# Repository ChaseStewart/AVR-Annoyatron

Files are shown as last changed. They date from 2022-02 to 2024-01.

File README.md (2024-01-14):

# AVR-Annoyatron
Documentation (https://chasestewart.github.io/AVR-Annoyatron/)

Rebuilding an undergrad embedded systems final project to reflect new knowledge and skills on a different MCU

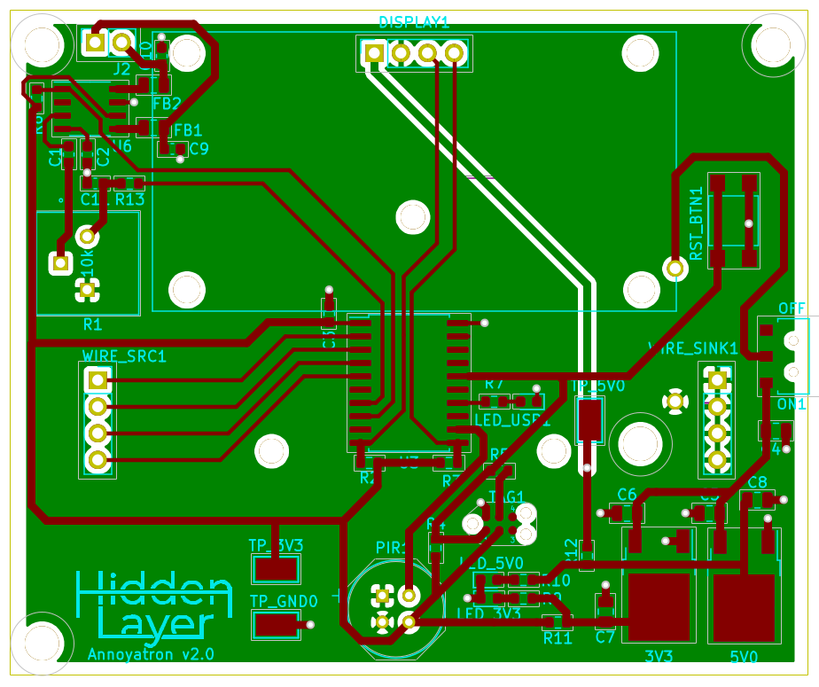
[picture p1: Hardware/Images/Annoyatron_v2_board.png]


# Author
[Chase E. Stewart](https://chasestewart.co) for [Hidden Layer Design](https://hiddenlayerdesign.com)

# Repository Layout
`/Hardware/Images/...` - Embeddable images of the schematic and board layout

`/Hardware/Board_Files/...` - Gerber files that can be used to order the circuit board

`/Software/AnnoyatronFW/...` - Firmware for the Annoyatron project, in the form of a Microchip Studio project

# Guides
* To learn more about Audio, read [here](Software/AnnoyatronFW/audio/README.md)
* To learn more about Programming the board, read [here](Software/README.md)

# Setup Instructions

## Hardware
* Order the board from a PCB manufacturer using the Board_Files
* Order the parts from an electronics company using `/Hardware/Annoyatron_v2_BOM.csv`
* Assemble the PCB

## Software
* Download [Python 3.10](https://www.python.org/) or similar if you don't have it (don't go too far back) and put it in your executable path
* Download [pymcuprog](https://pypi.org/project/pymcuprog/) using pip or whatever works
* Download [Microchip Studio](https://www.microchip.com/en-us/tools-resources/develop/microchip-studio) and load the project from `/Software/AnnoyatronFw/...`
* Set up the custom programming tool in Microchip Studio to suit your configuration 
  - Mine was `pymcuprog write -t uart -d attiny1606 -u COM12 -f "$(MSBuildProjectDirectory)\Debug\AnnoyatronFW.hex" -v info -c 57600 --verify`
* Acquire a [Tag-Connect programming tool](https://www.tag-connect.com/product/tc2030-pkt-icespi-nl) and connect it to a [USB-to-serial dongle](https://www.sparkfun.com/products/12731) to do the flashing 
  - *NOTE: Don't install a battery until you've successfully flashed the code and the board appears to be working over USB power!!*
* You will need to use a `pymcuprog` erase command between every flash to make sure your program will be successfully verified
  - Mine was `pymcuprog erase -t uart -u COM12 -d attiny1606`

## Running the program
* Remove the programming header and install a 9-volt battery
* Turn on the power using the switch
* Move or wave to trigger the PIR sensor, and then cut the proper wire before time runs out

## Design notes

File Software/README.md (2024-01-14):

# Programming the board

## Programming Interface
This project uses the [UPDI Programming Interface](https://onlinedocs.microchip.com/pr/GUID-DDB0017E-84E3-4E77-AAE9-7AC4290E5E8B-en-US-4/index.html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) in order to flash the ATTiny1606 with code changes. In this project, the TagConnect 6 pin No Legs footprint was used for programming to save board space and to avoid populating a big 2x3 header. 

## Hardware Needed
You will need the following to flash your board
* A USB cable
* A populated Annoyatron Board
* An [FTDI](https://www.adafruit.com/product/284)-to-[USB interface](https://www.sparkfun.com/products/9873) - Many options are available and counterfeit chips can be found, but Sparkfun and Adafruit are probably safe bets if you don't know what to get
* A [TagConnect TC2030-PKT-NL 6-pin connector](https://www.digikey.com/en/products/detail/tag-connect-llc/TC2030-PKT-NL/18713762)
* A [TagConnect Board-Retaining End Clip](https://www.digikey.com/en/products/detail/tag-connect-llc/TC2050-CLIP-3PACK/12318009)

**NOTE**: I have a probably-counterfeit FTDI debugger that works for most things including communicating over UART and flashing other types of boards, but that debugger just does not work with this UPDI- this is the reason for the warning in the FTDI-to-USB entry. 

## Steps and Images
First you will need to properly connect the FTDI debugger pins to the TagConnect cable, and connect the FTDI debugger to a USB cable. When that is done it should look like this:
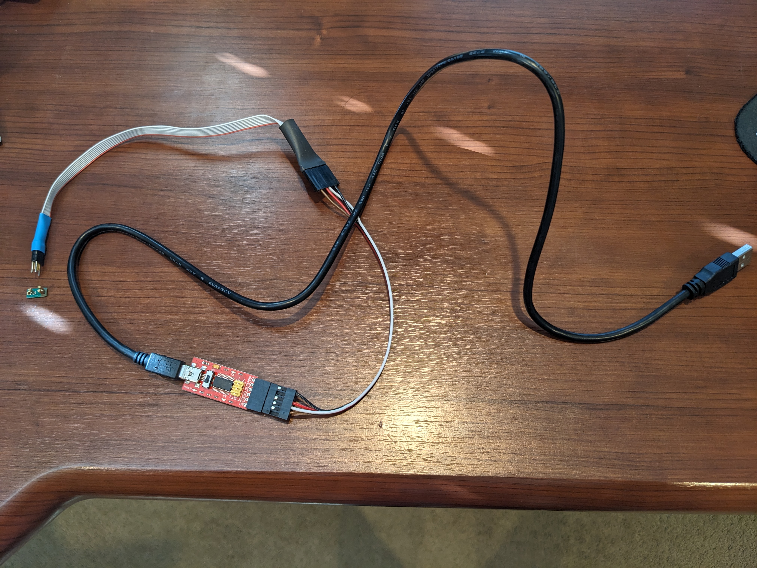
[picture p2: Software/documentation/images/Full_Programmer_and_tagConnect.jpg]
Image of the full programming tool including TagConnect cable


I wound up making a custom F-F Dupont-connector cable to ensure proper orientation (I use the black GND cable and red VCC to visually confirm orientation every time), 
but you can use jumper connectors or whatever you need. I populated the TXD, RXD, GND, and VCC pins only for this UPDI connector. 
Image of just the FTDI-to-USB device and its connector cable

Now that you have the cable, you are going to look for this `TAG1` footprint on the board that looks like this. 
The feet of the TagConnect cable will go through the holes and then the little cap can be placed on the far side of the board to secure the cable. Spring tension will keep the pogo pins electrically connected the 6 circular pins on the face of the PCB. 
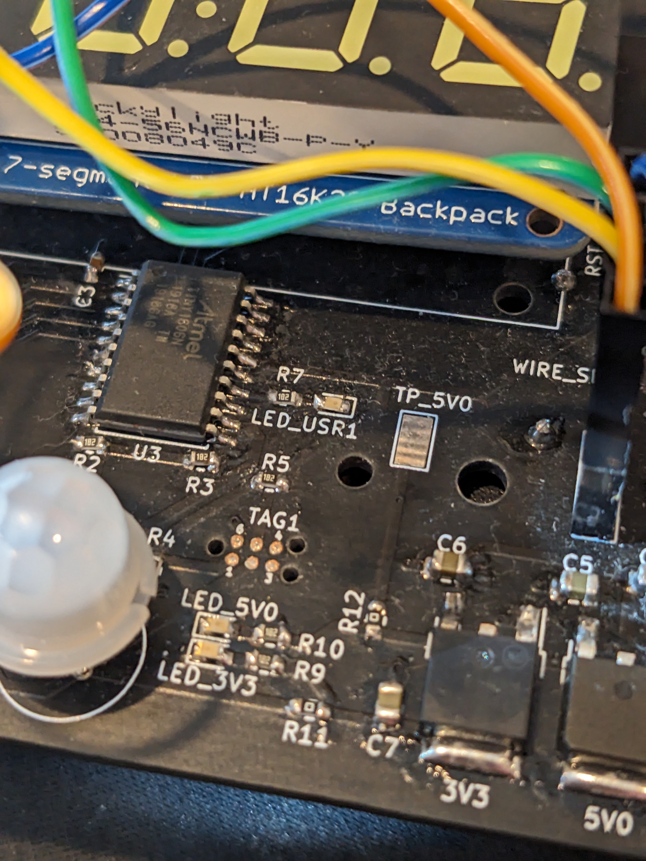
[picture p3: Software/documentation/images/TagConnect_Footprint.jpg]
Image of the location on the PCB where the TagConnect can be attached


When you put it all together it should look like this:
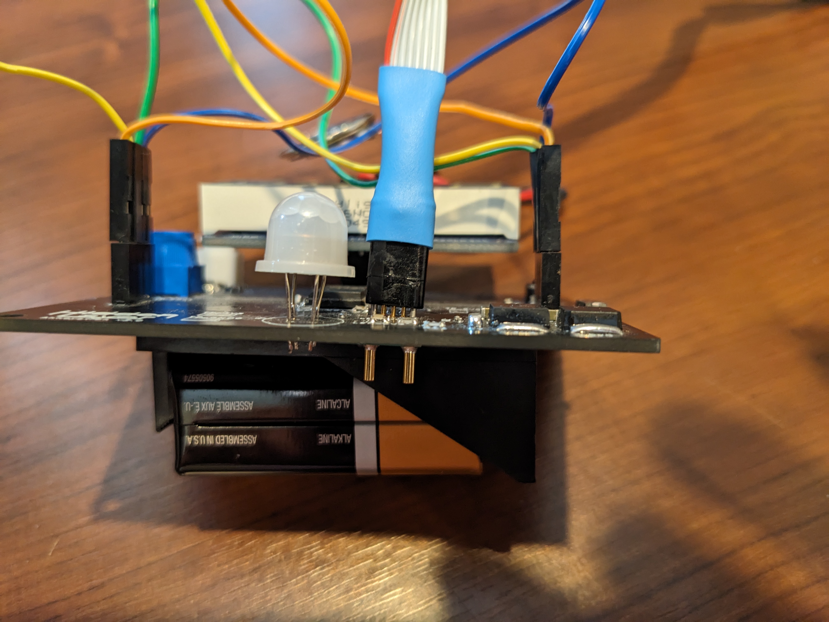
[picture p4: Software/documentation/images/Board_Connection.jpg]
Image of the TagConnect cable connected to the board


**NOTE:** When you have the board connected to a computer, **ENSURE THE 9-VOLT BATTERY IS REMOVED OR THE POWER SWITCH IS OFF**

Now use the scripts in the Scripts folder or set up a programming command in Microchip Studio and you should be able to flash your board
As a basic check, you can try to read the fuses with `ReadATTinyResetFuse.ps1`. If everything appears connected, but the UPDI check is failing, check your connector's pins to ensure TX, RX, VCC, and GND are properly connected, and you can also gently wiggle the tag-connect cable a bit and try again.

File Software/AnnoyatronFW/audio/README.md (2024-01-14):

# AUDIO Readme
This section describes audioArrays.h and the process that was undertaken to get the audio working

## Author
[Chase E Stewart](https://chasestewart.co) for [Hidden Layer Design](https://hiddenlayerdesign.com)

## Overview
The annoyatron project is configured to use [split PWM output](https://ww1.microchip.com/downloads/en/AppNotes/TB3217-Getting-Started-with-TCA-90003217A.pdf) from its [ATTiny 1606](https://ww1.microchip.com/downloads/en/DeviceDoc/ATtiny806_1606_Data_Sheet_40002029A.pdf) CPU in order to generate audio. Audio is stored as C byte arrays in flash. These are fed to the comparator of the TCA0 clock, which uses its PWM Waveform output to control an audio amplifier IC's input pin, which then goes out to a cheap electronics speaker. There are 3 sounds that are used in the project:
* Siren - A short looping frequency chirp that plays repeatedly as the timer counts down. Stops when the timer runs out or when you cut a wire or wires
* YouWin - The phrase "You Win", played once when you win (cut the right wire before time runs out)
* YouLose - The phrase "You Lose", played once when you lose (cut multiple wires, cut the wrong wire, or time runs out)

### Audio Challenges
There are a number of challenges that stymie an easy solution to the audio problem:

1. The split comparator in the TCA0 that is used for PWM audio is only 8-bit sized. So you must use 8-bit audio.
1. You have literally 16kB of flash to work with. This is rather extreme in terms of resource constraint in this day and age. NOTE this could be alleviated easily enough by adding a memory chip, but the original project this is based on was also similarly constrained.

The space constraint is such that you must squeeze every possible shortcut out of the audio such that it still mostly serves your purposes. This includes shortening, bit crushing, downsampling, filtering, and anything you could imagine. It took a lot of tricks from my ECE background and audio tricks from my studio to result in just a quick and intelligible-enough "you win!", "you lose!", and siren noise. The challenge was interesting enough to me that I felt it merited this write-up 

### Audio Solution
Here are the things I had to do in order to get the audio working such as it does now:

1. First, record "you lose" and "you win" audio under the best circumstances possible (I used a quality microphone and audio interface)
1. These should ideally be somewhere from 0.7 to 1.3 seconds long to make your later editing easier
1. Process it for great clarity including compression, breath control, and EQ
1. Ableton Live has a "Telephone Audio" EQ that mostly just band-passes only 500Hz to 2kHz which was crucial for my eventual solution
1. Export that audio in mono at the lowest bitrate and sample frequency possible in your recording software (I started with 22050Hz, 16-bit audio)
1. Now open the audio in [Audacity](https://www.audacityteam.org/), lower the project rate to 8kHz, run `Tracks->Resample->8kHz` on the whole sample
1. Compress the audio further if necessary using `Effect->Compressor...`; the default settings that come up should be fine unless you understand compression
1. If your audio is longer than 0.7 seconds for either youWin or youLose, you may find the `Effect->Change Tempo...` effect extremely helpful in getting your samples to fit within the 16kB of flash
1. [Export from Audacity in 8 bit](https://forum.audacityteam.org/t/is-there-a-way-to-convert-a-song-into-8-bit/35388) into this folder where [ParseWaveFile.py](parseWaveFile.py) exists
1. Run the parseWaveFile.py Python Helper Script to create header files 
1. Copy the C-structs generated by the Python Helper Script into audioArrays.h, covering the current youWin and youLose structs.
1. Now hit Compile in the project, and hope for no errors related to overrunning the Flash. If the code compiles it will fit properly and work in the device
1. Now test the board in success and failure case, and ensure the samples sound clear and sound like what you want. NOTE The quality just won't be that good, you have 16kB to work with! 
1. I had to slightly pitch up my audio in order to deal with some oversampling in the TCA0 code. You can do this by reopening Audacity and using `Effect->Change Pitch...` somewhere like 10-20%

NOTE: The siren noise is mostly original from the 2009/2010 project. I guess my lab partner and I had solved this one time before, but did not write up the process to fit the audio in the previous CPU last time. 

### Python Script
The recommended way to use the [ParseWaveFile.py](parseWaveFile.py) script is to download the community version of PyCharm, and make a new project in the Software/AnnoyatronFW/audio project. You can use a venv and a python3 interpreter and it should work right out of the box- the [wave library](https://docs.python.org/3/library/wave.html) that is used is a standard python library. You can bring .WAV files right into the audio/ folder, and by default your generated headers will be created in the Outputs/ folder- the .gitignore files are set up such that your inputs and outputs won't be accidentally contributed to the repository.

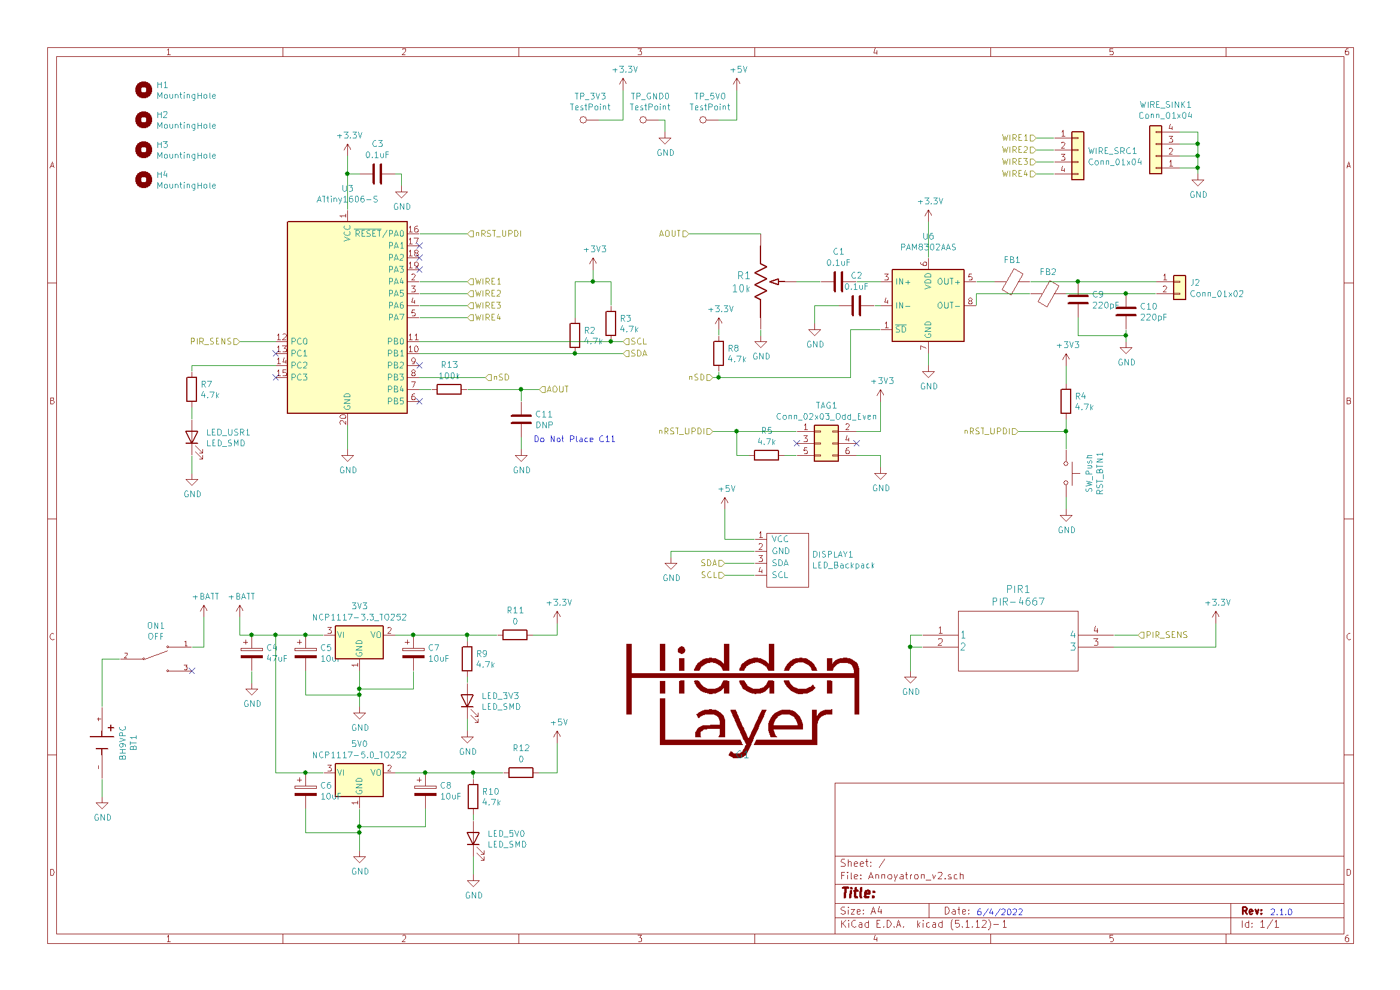
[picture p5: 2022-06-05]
Hardware/Images/Annoyatron_v2_schematic.png

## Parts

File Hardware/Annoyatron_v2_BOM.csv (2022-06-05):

Reference | Quantity | Value | Description | Footprint | Datasheet
3V3 | 1 | NCP1117-3.3_TO252 | Linear Regulator 3.3V | Package_TO_SOT_SMD:TO-252-2 | http://www.onsemi.com/pub_link/Collateral/NCP1117-D.PDF
5V0 | 1 | NCP1117-5.0_TO252 | Linear Regulator 5V | Package_TO_SOT_SMD:TO-252-2 | http://www.onsemi.com/pub_link/Collateral/NCP1117-D.PDF
BT1 | 1 | BH9VPC | 9V Battery Holder | parts:BAT_BH9VPC | https://www.memoryprotectiondevices.com/datasheets/BH9VPC-datasheet.pdf
C1 C2 C3 | 3 | 0.1uF | SMD Capacitor | Capacitor_SMD:C_0603_1608Metric | http://www.passivecomponent.com/wp-content/uploads/datasheet/WTC_MLCC_General_Purpose.pdf
C4 | 1 | 47uF | SMD Capacitor | Capacitor_SMD:C_0805_2012Metric | http://www.passivecomponent.com/wp-content/uploads/datasheet/WTC_MLCC_General_Purpose.pdf
C5 C6 C7 C8 | 4 | 10uF | SMD Capacitor | Capacitor_SMD:C_0805_2012Metric | http://www.passivecomponent.com/wp-content/uploads/datasheet/WTC_MLCC_General_Purpose.pdf
C9 C10 | 2 | 220pF | SMD Capacitor | Capacitor_SMD:C_0603_1608Metric | http://www.passivecomponent.com/wp-content/uploads/datasheet/WTC_MLCC_General_Purpose.pdf
DISPLAY1 | 1 | Adafruit_1002 | LED Display Backpack | custom:LED_Backpack | https://cdn-shop.adafruit.com/datasheets/ht16K33v110.pdf
FB1 FB2 | 2 | Ferrite_Bead | SMD Ferrite Bead | Capacitor_SMD:C_0805_2012Metric | https://www.we-online.com/katalog/datasheet/74279207.pdf
J2 | 1 | Conn_01x02 | JST Male 01x02 Conn | Connector_PinSocket_2.54mm:PinSocket_1x02_P2.54mm_Vertical | https://www.jst-mfg.com/product/pdf/eng/eEH.pdf
LED_USR1 LED_3V3 LED_5V0 | 3 | LED_SMD | SMD LED | LED_SMD:LED_0603_1608Metric | https://www.we-online.com/katalog/datasheet/150060VS55040.pdf
ON1 | 1 | SW_AYZ0102AGRLC | Switch | parts:SW_AYZ0102AGRLC | https://www.ckswitches.com/media/1431/ayz.pdf
PIR1 | 1 | PIR-4667 | PIR Sensor | footprints:4667 | https://cdn-shop.adafruit.com/product-files/4667/4667_C15116.pdf
R1 | 1 | 10k | Trim Pot 10k | custom:3386P-1-103TLF | https://www.bourns.com/docs/Product-Datasheets/3386.pdf
R11 R12 | 2 | 0 | SMD Resistor | Resistor_SMD:R_0603_1608Metric | https://www.yageo.com/upload/media/product/productsearch/datasheet/rchip/PYu-RC_Group_51_RoHS_L_11.pdf
R13 | 1 | 100k | SMD Resistor | Resistor_SMD:R_0603_1608Metric | https://www.yageo.com/upload/media/product/productsearch/datasheet/rchip/PYu-RC_Group_51_RoHS_L_11.pdf
R2 R3 R4 R5 R7 R8 R9 R10 | 8 | 4.7k | SMD Resistor | Resistor_SMD:R_0603_1608Metric | https://www.yageo.com/upload/media/product/productsearch/datasheet/rchip/PYu-RC_Group_51_RoHS_L_11.pdf
RST_BTN1 | 1 | SW_Push | Pushbutton | Button_Switch_SMD:SW_SPST_TL3305A | https://sten-eswitch-13110800-production.s3.amazonaws.com/system/asset/product_line/data_sheet/213/TL3305.pdf
TAG1 | 1 | Conn_02x03_Odd_Even | Tag-Connect 6pin No Legs | custom:TC2030-IDC-NL | https://www.tag-connect.com/wp-content/uploads/bsk-pdf-manager/2019/12/TC2030-IDC-NL-Datasheet-Rev-B.pdf
TP_GND0 TP_3V3 TP_5V0 | 3 | TestPoint | Test Points | TestPoint:TestPoint_Keystone_5019_Minature | https://www.keyelco.com/product-pdf.cfm?p=1357
U3 | 1 | ATtiny1606-S | ATTiny1606 Microcontroller | Package_SO:SOIC-20W_7.5x12.8mm_P1.27mm | http://ww1.microchip.com/downloads/en/DeviceDoc/ATtiny806_1606_Data_Sheet_40002029A.pdf
U6 | 1 | PAM8302AAS | IC Class-D Audio Amplifier | Package_SO:SOP-8_3.9x4.9mm_P1.27mm | https://www.diodes.com/assets/Datasheets/PAM8302A.pdf
WIRE_SINK1 WIRE_SRC1 | 2 | Conn_01x04 | Female 01x04 Header Socket | Connector_PinSocket_2.54mm:PinSocket_1x04_P2.54mm_Vertical | https://app.adam-tech.com/products/download/data_sheet/203013/rs1-xx-g-data-sheet.pdf
SPEAKER | 1 | CDM-20008 | Speaker | N/A | https://www.cuidevices.com/product/resource/cdm-20008.pdf

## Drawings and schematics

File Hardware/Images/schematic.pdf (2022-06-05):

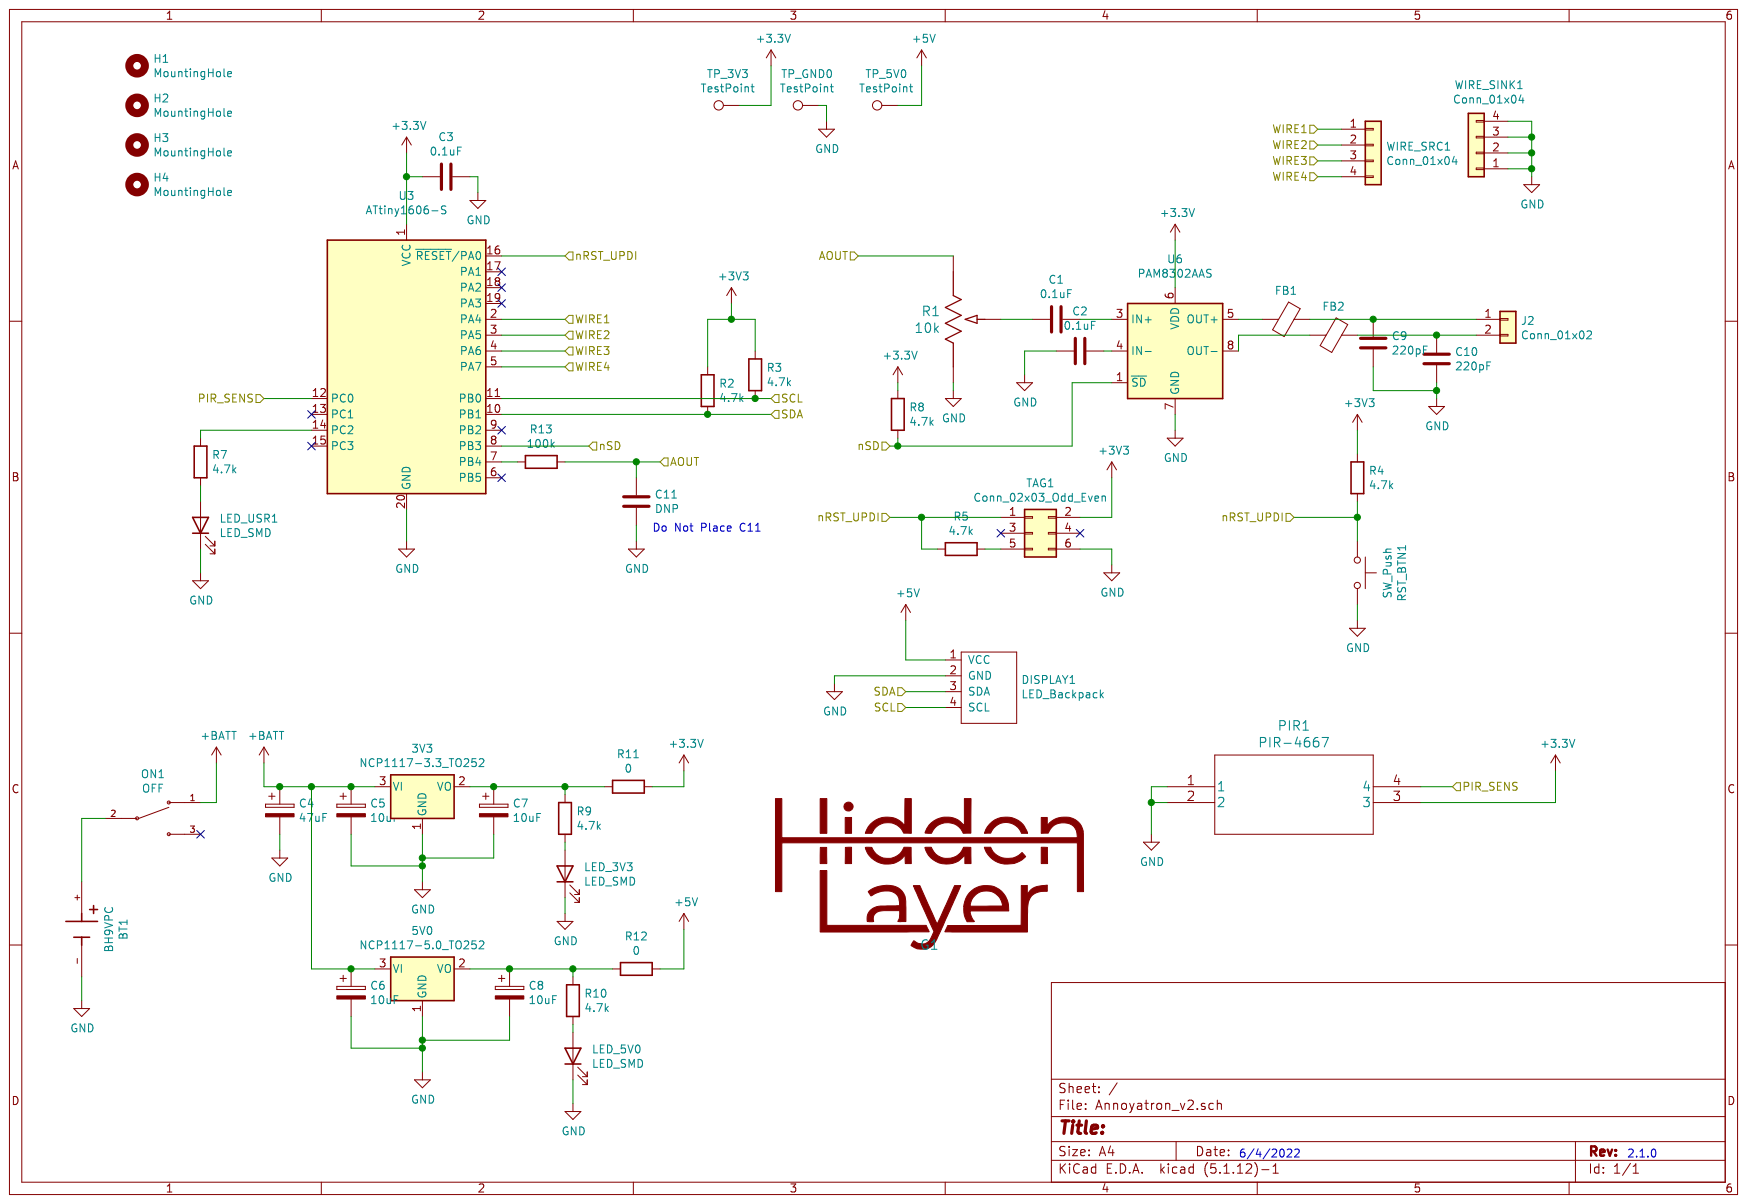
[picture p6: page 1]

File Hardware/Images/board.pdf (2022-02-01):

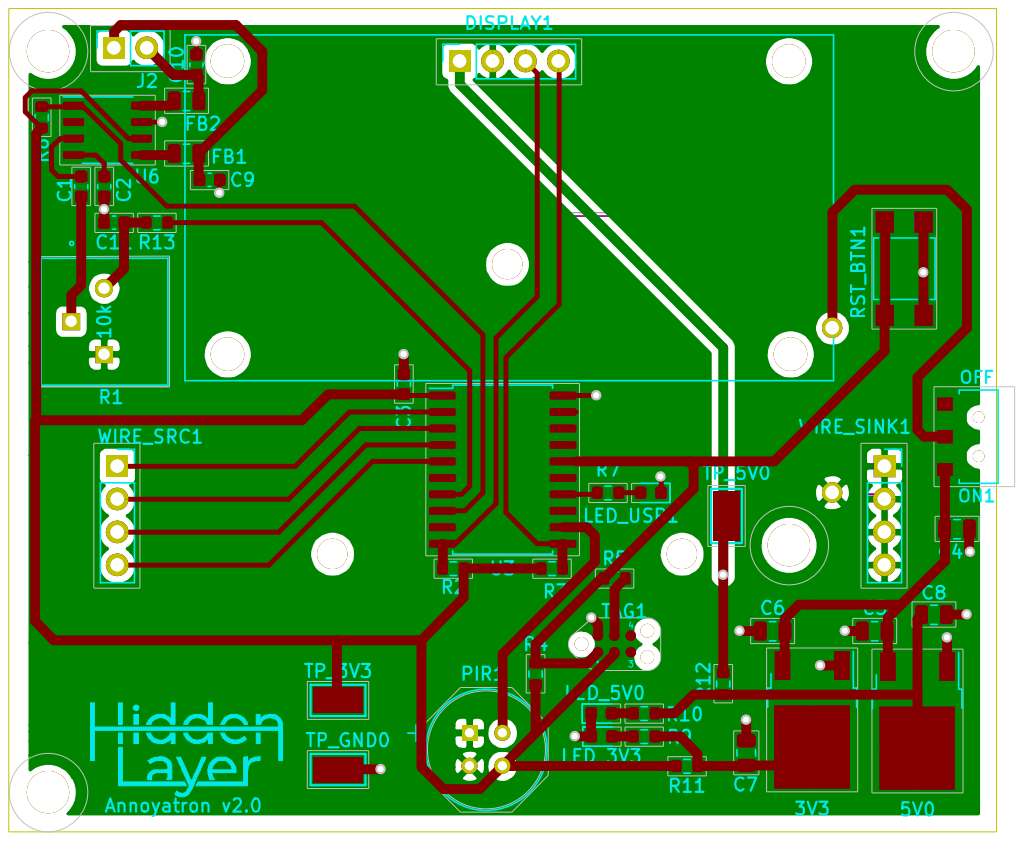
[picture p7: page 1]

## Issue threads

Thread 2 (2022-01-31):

Add volume control along AIN to PAM8302

ChaseStewart, 2022-01-31:
Currently the output through the speaker is extremely loud. For what it's worth an adafruit part included a 10k trim pot across AIN+ and AIN-, but perhaps breadboarding using a breakout will be more effective here than prescribing a solution. Task here is to get the audio to "conversation level" from "alarming" and put that in the next circuit.

ChaseStewart, 2022-02-01:
Resolved via https://github.com/ChaseStewart/AVR-Annoyatron/commit/2c54d1ed562497d5df5cedb5d4fecbfe4357054d

Closed 2022-02-01.

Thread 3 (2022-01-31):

Remove 100mil programming headers

ChaseStewart, 2022-01-31:
Tag-Connect is working, so lets un-clutter the board a bit and just use the tag-connect!

ChaseStewart, 2022-02-01:
Resolved via https://github.com/ChaseStewart/AVR-Annoyatron/commit/2c54d1ed562497d5df5cedb5d4fecbfe4357054d

Closed 2022-02-01.

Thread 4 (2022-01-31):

Add a few test points

ChaseStewart, 2022-01-31:
At least 5V, 3V3, and GND should have clip-in test points for next revision

ChaseStewart, 2022-02-01:
Resolved via https://github.com/ChaseStewart/AVR-Annoyatron/commit/2c54d1ed562497d5df5cedb5d4fecbfe4357054d

Closed 2022-02-01.

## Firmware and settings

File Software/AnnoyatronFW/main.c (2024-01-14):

/*!
 * @file main.c
 *
 * @mainpage Annoyatron v2.0 Firmware
 *
 * @section intro_sec Introduction
 *  This documentation describes firmware for an AVR ATTiny1606 on a custom-designed PCB to become a James Bond movie prop. 
 *  On boot, A PIR sensor is used to detect motion nearby. When motion is detected, a timer counts down and a sound begins to play.
 *  The user is presented with four wires to cut- cutting the right one before the timer hits zero will play the success noise, and cutting any other wire or letting
 *  the timer fully count down without cutting any wires at all will play the failure noise. Either way, the success or failure state each play a one-shot noise,
 *  and then put the MCU in sleep mode until it is reset. 
 *
 * @section history History
 *  This project recreates an undergraduate project at Rice University in 2013-2014. 
 *  The midterm group project for ELEC 327 required designing and building an embedded system based on the Texas Instruments MSP430
 *  and some amount of sensors and/or actuators. We wound up creating what we described as a "James Bond movie prop", and with only a few fly-wires
 *  managed to get it working well enough to pick up an A grade. Despite my enthusiasm and hard work, my partner was much more experienced in PCB design
 *  and very good at software to boot- so honestly I could not at the time have gotten the project to work by myself. I wanted to redesign the project around a
 *  more modern microcontroller, and to do a solo implementation of the PCB now that I am able, adding some improvements along the way.
 *  
 * @section dependencies Dependencies
 *  The project file for this code is for Microchip Studio (based on the Eclipse IDE), which you can get from <a href="microchip.com/en-us/tools-resources/develop/microchip-studio">Microchip's website</a>.
 *  This code runs on an ATTiny1606- ATTiny models with less memory than 16K will not be able to hold the audio arrays.
 *  You will need Python3 and `pymcuprog` to actually flash the MCU with the compiled code.
 *  PCB setup, assembly, and connectivity to your computer is left as an exercise to the reader ;)
 * 
 * @section author Author
 *  Chase E. Stewart for <a href="https://www.hiddenlayerdesign.com">Hidden Layer Design</a>
 *
 * @section source_code Source Code 
 * <a href="https://github.com/ChaseStewart/AVR-Annoyatron">AVR-Annoyatron on GitHub</a>
 */
#include "audio/audioArrays.h"
#include "main.h"
#include "I2C.h"
#include "SevenSeg.h"
#include "random.h"
 
#define __DELAY_BACKWARD_COMPATIBLE__  //< Required to be defined for delay_msec to work
#include <util/delay.h>
#include <stdbool.h>
#include <xc.h>
#include <avr/io.h>
#include <avr/interrupt.h>
#include <avr/sleep.h>

/* static functions */
static void initPeripherals(void);
static void initClocks(void);
static void initCutWires(void);
static void initPIR(void);
static void initLED(void);
static void initAudio(void);
static void initCountdownTimer(void);
static void initADC(void);
static bool PIRisTriggered(void);
static bool wireIsCut(void);
static bool properWireIsCut(uint8_t inWire);
static void setAudioIsEnabled(bool isAudioEnabled);
static void setLed(bool isLedSet);

/* volatile variables */
volatile uint32_t audioIdx;  ///< Index into playing audio array from audioArrays.h
volatile bool ADCResRdy;  ///< True if ADC has results for random sample, else False
volatile bool counterRollover;  ///< True if countdown time has run out, else False
volatile uint32_t pirHighCount;  ///< How many times has the PIR sensor consecutively been tripped
volatile uint32_t pirLowCount;  ///< How many times has the PIR sensor consecutively been tripped
volatile uint32_t tcbCount;  ///< Countdown timer count that is used to set 7 seg display
volatile board_state_t boardState; ///< Current state enumeration of state machine
volatile blink_state_t blinkState;  ///< State machine for blinking LED during countdown
volatile uint32_t blinkCount;  ///< Actual counter value for nonblocking LED blink

/* non-volatile variables */
uint8_t safeWire;  ///< integer index [0-3] of wire selected to be proper wire
uint8_t cut_wire_pos_array[NUM_CUT_WIRES] = {PIN4_bm, PIN5_bm, PIN6_bm, PIN7_bm};  ///< GPIO bitmask for the wires-to-be-cut
blink_state_t blinkReloadState[4] = {blink_state_1_high, blink_state_2_high, blink_state_3_high, blink_state_4_high};  ///< Location to restart the blink pattern


/*!
 * @brief Perform initializations and then implement state machine
 * 
 * @return 0 for success, else failure
 */
int main(void)
{
   audioIdx = 0;
   pirHighCount = 0;
   pirLowCount = 0;
   ADCResRdy = false;
   counterRollover = false;
   tcbCount = 10*100;
   blinkCount = BLINK_COUNT_SHORT;
   initPeripherals();
   set_sleep_mode(SLEEP_MODE_PWR_DOWN);
   sei();
   
   random_init(adcGetSeed());
   safeWire = (uint8_t) (random() % NUM_CUT_WIRES);
   blinkState = blinkReloadState[safeWire];
   writeAllDigits(safeWire + 1);

   ledUsrBlink(3, 500);

   writeAllDigits(SEVENSEG_NONE);   
   TCB0.CTRLA = TCB_ENABLE_bm;

   boardState = board_state_sleep;
   setLed(false);
   PORTC.PIN0CTRL |= PORT_ISC_BOTHEDGES_gc;
   
   while(1)
   {

      switch(boardState)
      {
		 case board_state_wire_setup:
			// waiting for the wires to be plugged in
			if (!wireIsCut())
			{
               sevenSegBlink(HT16K33_BLINK_OFF);
               writeAllDigits(SEVENSEG_NONE);
               boardState = board_state_sleep;
			   pirHighCount = 0;
			   pirLowCount = 0;
               setLed(false);
               PORTC.PIN0CTRL |= PORT_ISC_BOTHEDGES_gc;
			}
			break;
			
         case board_state_sleep:
			sleep_mode();
		    break;
		 
         case board_state_waiting:
		    if (wireIsCut())
			{
               sevenSegBlink(HT16K33_BLINK_1HZ);
               writeAllDigits(SEVENSEG_DASH);
               boardState = board_state_wire_setup;
               setLed(false);
			}
            break;
         
         case board_state_countdown:
            // Actively update count until wire is cut or counter rolls over
            setSevenSegValue(0, (tcbCount / 1000) % 10);
            setSevenSegValue(1, (tcbCount / 100)  % 10);
            setSevenSegValue(2, 0x02);
            setSevenSegValue(3, (tcbCount / 10) % 10);
            setSevenSegValue(4, tcbCount % 10);
            writeSevenSeg();
         
            if (counterRollover)
            {
			   audioIdx = 0;
               boardState = board_state_failure;
               counterRollover = false;
               sevenSegBlink(HT16K33_BLINK_2HZ);
               writeAllDigits(0);
               TCB0.CTRLA = 0;
            }
            else if (wireIsCut())
            {             
               if (properWireIsCut(safeWire))
               {
				  audioIdx = 0;
                  boardState = board_state_success;
                  sevenSegBlink(HT16K33_BLINK_HALFHZ);
                  writeSevenSeg();
               }
               else
               {
				  audioIdx = 0;
                  boardState = board_state_failure;
                  writeAllDigits(0);
                  sevenSegBlink(HT16K33_BLINK_2HZ);
               }
            }
            break;
         
         case board_state_failure:
		    if (audioIdx >= sizeof(youLose))
			{
				setAudioIsEnabled(false);
				boardState = board_state_done;
				setLed(false);
			}
            break;
			
		case board_state_success:
		    if (audioIdx >= sizeof(youWin))
		    {
			    setAudioIsEnabled(false);
			    boardState = board_state_done;
			    setLed(false);
		    }
			break;
			
         case board_state_done:
		    // get stuck forever
			sleep_mode();
			break;
		 
         default:
            // should never get here!
            ledUsrBlink(0, 1000);
      }
   }
   // should never get here!
   return 0;
}

/*!
 * @defgroup HardwareInit
 * Functions to initialize the hardware for this project
 */

/*!
 * @ingroup HardwareInit
 *
 * @brief Setup all peripherals.
 *
 * @param None
 *
 * @return None
 */
static void initPeripherals(void)
{
   initClocks();
   initCountdownTimer();
   initLED();
   initPIR();
   I2C_init();
   initSevenSeg();
   initADC();
   initAudio();
   initCutWires();
}

/*!
 * @ingroup HardwareInit
 *
 * @brief Setup clock registers.
 *
 * @param None
 *
 * @return None
 */
static void initClocks(void)
{
   CLKCTRL.MCLKCTRLA |= CLKCTRL_CLKOUT_bm | CLKCTRL_CLKSEL_OSC20M_gc;
   CLKCTRL.MCLKCTRLB |= CLKCTRL_PDIV_16X_gc | CLKCTRL_PEN_bm;
}

/*!
 * @ingroup HardwareInit
 *
 * @brief Startup the timer to measure centi-seconds.
 * TODO get CCMP just right, validate with scope
 *
 * @param None
 *
 * @return None
 */
static void initCountdownTimer(void)
{
   TCB0.CTRLB = TCB_CNTMODE_INT_gc;
   TCB0.INTFLAGS = 1;
   TCB0.EVCTRL = TCB_CAPTEI_bm;
   TCB0.INTCTRL = TCB_CAPTEI_bm;
   TCB0.CNT = 0;
   TCB0.CCMP = 0xFFFF;
   TCB0.CTRLA = 0;
}

/*!
 * @ingroup HardwareInit
 *
 * @brief Setup the TCA0 timer and PWM output to the audio IC.
 *  Also setup the ~SHDN pin 
 *
 * @param None
 *
 * @return None
 */
static void initAudio(void)
{
   /*
    *	set Audio ~SHDN pin to output low for now
    */
   PORTB.DIRSET = PIN3_bm;
   setAudioIsEnabled(false);

   /*
    *	Setup PORTMUX to provide alternate WO1 output
    */
   PORTMUX.CTRLC = PORTMUX_TCA01_bm;

   /*
    *	setup underflow interrupt
    */
   TCA0.SPLIT.INTCTRL = TCA_SPLIT_LUNF_bm;

   /*
    *	setup PWM
    */
   PORTB.DIRSET = PIN4_bm; // Set PWM pin to output
   TCA0.SPLIT.CTRLD = TCA_SPLIT_SPLITM_bm; // Enable split mode based on v1.9.9 pinout
   TCA0.SPLIT.CTRLB |= (TCA_SPLIT_LCMP1EN_bm); // LCMP1 corresponds to our WO1
   TCA0.SPLIT.LPER  = 0xFF; // use whole 8 bit array
   TCA0.SPLIT.LCMP1 = 0; // this will be controlled by the audioArray
   TCA0.SPLIT.CTRLA = (TCA_SPLIT_CLKSEL_DIV2_gc | TCA_SPLIT_ENABLE_bm);
}


/*!
 * @ingroup HardwareInit
 *
 * @brief Set up the PIR sensor for sensor readings.
 *
 * @param None
 *
 * @return None
 */
static void initPIR(void)
{
   PORTC.DIRCLR = PIN0_bm;
   PORTC.PIN0CTRL &= ~PORT_PULLUPEN_bm;
}

/*!
 * @ingroup HardwareInit
 *
 * @brief Set up the GPIO for the four cut-wires.
 *
 * @param None
 *
 * @return None
 */
static void initCutWires(void)
{
   PORTA.DIRCLR = CUT_WIRES_bm;
   PORTA.PIN4CTRL = PORT_PULLUPEN_bm;
   PORTA.PIN5CTRL = PORT_PULLUPEN_bm;
   PORTA.PIN6CTRL = PORT_PULLUPEN_bm;
   PORTA.PIN7CTRL = PORT_PULLUPEN_bm;
}

/*!
 * @ingroup HardwareInit
 *
 * @brief Set up the user LED.
 *
 * @param None
 *
 * @return None
 */
static void initLED(void)
{
   PORTC.DIRSET = PIN2_bm;
}

/*!
 * @ingroup HardwareInit
 *
 * @brief Setup ADC to get random sample.
 *
 * @param None
 *
 * @return None
 */
static void initADC(void)
{
   ADC0.MUXPOS = ADC_MUXPOS_AIN1_gc;
   ADC0.CTRLA |= ADC_ENABLE_bm;
   ADC0.INTCTRL = ADC_RESRDY_bm;
}

/*!
 * @defgroup ISRs
 * Interrupt service routines with custom handlers for this project
 */

/*!
 * @ingroup ISRs
 * @brief Timer Interrupt for countdown timer TCB0.
 *
 * @param TCB0_INT_vect 
 *  Unused parameter required by interface
 *
 * @return None
 */
ISR(TCB0_INT_vect)
{
   TCB0.INTFLAGS = 1;
   
   if (boardState == board_state_countdown)
   {   
      tcbCount--;
	  blinkCount--;
	  
	  if (!blinkCount)
	  {
	    blinkState--;
		if (blinkState == blink_state_0)
		{
			setLed(true);
			blinkState = blinkReloadState[safeWire];
			blinkCount = BLINK_COUNT_SHORT;
		}
		else if (blinkState == blink_state_1_low)
		{
			setLed(false);
			blinkCount = BLINK_COUNT_LONG;
		}
		else
		{
			blinkCount = BLINK_COUNT_SHORT;
			setLed( (blinkState % 2) ? false : true);
		}
	  }
	  
      if (tcbCount == 0)
      {
         counterRollover = true;
         tcbCount = 10 * 100;
      }
   }      
   else if (boardState == board_state_waiting)
   {
	  /** 
	   * start counting towards the configured amount of
	   * PIR detects until proceeding to countdown mode
	   */
	  if (PIRisTriggered())
	  {
		  pirHighCount += 1;
		  pirLowCount = 0;
		  if (pirHighCount >= PIR_HIGH_COUNT_TO_COUNTDOWN)
		  {
			  boardState = board_state_countdown;
			  setAudioIsEnabled(true);
			  setLed(false);
		  }
	  }
	  /** 
	   * start counting towards the separately configured amount of
	   * PIR non-detects until proceeding to PWR_DOWN sleep mode
	   */
	  else
	  {
		  pirHighCount = 0;
		  pirLowCount += 1;		  
		  if (pirLowCount >= PIR_LOW_COUNT_TO_SLEEP)
		  {
			  boardState = board_state_sleep;
			  setAudioIsEnabled(false);
			  setLed(false);
              PORTC.PIN0CTRL |= PORT_ISC_BOTHEDGES_gc;
		  }
	  }
   }
}

/*!
 * @ingroup ISRs
 * @brief TCA interrupt for PWM timer, to load next audio sample into compare register.
 *
 * @param TCA0_LUNF_vect 
 *  Unused parameter required by interface
 * 
 * @return None
 */
ISR(TCA0_LUNF_vect)
{
   TCA0.SPLIT.INTFLAGS = TCA_SPLIT_LUNF_bm;
   switch (boardState)
   {
      case board_state_countdown:
         TCA0.SPLIT.LCMP1 = (siren[audioIdx]);
         audioIdx = (audioIdx < sizeof(siren)) ? audioIdx + 1 : 0;
		 break; 
	  case board_state_success:
         TCA0.SPLIT.LCMP1 = (youWin[audioIdx]);
         audioIdx = (audioIdx < sizeof(youWin)) ? audioIdx + 1 : audioIdx;
	     break;
		 
	  case board_state_failure:
         TCA0.SPLIT.LCMP1 = (youLose[audioIdx]);
         audioIdx = (audioIdx < sizeof(youLose)) ? audioIdx + 1 : audioIdx;
	     break;

      default:
         return;
   }
}

/*!
 * @ingroup ISRs
 * @brief ADC interrupt when ADC results are ready to be taken.
 * 
 * @param ADC0_RESRDY_vect
 *  Unused parameter required by interface
 *
 * @return None
 */
ISR(ADC0_RESRDY_vect)
{
   ADC0.INTFLAGS = ADC_RESRDY_bm;
   ADC0.CTRLA &= !ADC_ENABLE_bm;
   ADC0.INTCTRL &= !ADC_RESRDY_bm;
   ADCResRdy = true;
}

/*!
 * @ingroup ISRs
 * @brief GPIO interrupt driven by PIR sensor when in sleep mode
 * 
 * @param PORTC_PORT_vect
 *  Unused parameter required by interface
 *
 * @return None
 */
ISR(PORTC_PORT_vect)
{
   if (PC0_INTERRUPT)
   {
	   // clear int flag so we don't repeatedly trigger
	   PC0_CLEAR_INTERRUPT_FLAG; 
	   
	   // disable this interrupt until state machine re-enables later
	   PORTC.PIN0CTRL &= ~PORT_ISC_BOTHEDGES_gc;
	   
	  // wake up to board_state_waiting
      boardState = board_state_waiting;
	  setLed(true);

   }
}

/*!
 * @brief Return whether any wire was cut.
 *
 * @param None
 * 
 * @return True if any wire has been cut, else False
 */
static bool wireIsCut(void)
{
   return PORTA.IN & CUT_WIRES_bm; // anything > 0 means a wire is cut
}

/*!
 * @brief Return whether only the proper wire was cut out of all wires.
 *
 * @param inWire
 *  The current state of cut and un-cut wires
 *
 * @return True if only the designated success wire is cut, else false
 */
static bool properWireIsCut(uint8_t inWire)
{
   return  ((PORTA.IN & CUT_WIRES_bm) == cut_wire_pos_array[inWire]);
}

/*!
 * @brief Set or clear the user LED according to the provided parameter
 *
 * @param isLedSet
 *  True means LED will be set, false means LED will be cleared
 *
 * @return None
 */
static void setLed(bool isLedSet)
{
	if (isLedSet)
	{
		PORTC.OUTSET = PIN2_bm;
	}
	else
	{
		PORTC.OUTCLR = PIN2_bm;
	}
}

/*!
 * @brief Return whether PIR sensor digital output is high at this moment.
 * 
 * @param None
 * 
 * @return True if PIR is currently triggered, else False
 */
static bool PIRisTriggered(void)
{
   return 0 != (PORTC.IN & PIN0_bm);
}

/*!
 * @brief Blink usr LED 'count'-many times at a period of 2 * 'blinkPeriodMsec'.
 *  NOTE: This is a blocking call!
 * 
 * @param count
 *  The number of times for the LED to blink- set to zero for infinite repetitions
 *  
 * @param blinkPeriodMsec
 *  The period between LED toggles in Msec
 */
void ledUsrBlink(uint8_t count, const int blinkPeriodMsec)
{
   uint8_t iter=0;

   while (!count || iter < count)
   {
      setLed(true);
      _delay_ms(blinkPeriodMsec);
      setLed(false);
      _delay_ms(blinkPeriodMsec);
      iter++;
   }
   // clear LED after blinking is done
   setLed(false);
}

/*!
 * @brief Set or clear audio output SHDN pin based on provided bool arg.
 * 
 * @param isAudioEnabled
 *   Set SHDN pin high if True, else set SHDN pin low
 * 
 * @return None
 */
static void setAudioIsEnabled(bool isAudioEnabled)
{
   if (isAudioEnabled) 
   {
      PORTB.OUTSET = PIN3_bm;
   }   
   else 
   {
      PORTB.OUTCLR = PIN3_bm;   
   }      
}

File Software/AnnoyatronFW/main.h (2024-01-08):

/*!
 * @file main.h
 *
 * Created: 12/12/2021 6:23:38 PM
 *
 * Author: Chase E. Stewart for Hidden Layer Design
 *
 * Contains configuration variables and definitions of shared items
 */ 

#include "stdbool.h"
#include "stdint.h"

#ifndef MAIN_H_
#define MAIN_H_

#define F_CPU 3333333  ///< Frequency of CPU in HZ

#define NUM_CUT_WIRES 4  ///< Number of slots for cut wires on the device
#define CUT_WIRES_bm (PIN4_bm | PIN5_bm | PIN6_bm | PIN7_bm) ///< bit masks for GPIO pins of cut wires

#define BLINK_COUNT_SHORT  5 ///< Duration between toggles for short LED blinks
#define BLINK_COUNT_LONG  11 ///< Duration between toggles for long LED blinks

#define PIR_HIGH_COUNT_TO_COUNTDOWN 350 ///< Compare val for pirHighCount until state -> board_state_countdown
#define PIR_LOW_COUNT_TO_SLEEP 350 ///< Compare val for pirLowCount until state -> board_state_sleep

#define PC0_INTERRUPT  PORTC.INTFLAGS & PIN0_bm  ///< True if the PortC pin0 GPIO interrupt fired
#define PC0_CLEAR_INTERRUPT_FLAG  PORTC.INTFLAGS |= PIN0_bm  ///< Clear the PortC pin0 interrupt flag bit

/** All of the possible states in the state machine */
typedef enum board_state_enum
{
   board_state_wire_setup,
   board_state_sleep,
   board_state_waiting,
   board_state_countdown,
   board_state_success,
   board_state_failure,
   board_state_done
} board_state_t;

/** State machine to hold the blinking pattern for different cut_wires options */
typedef enum blink_state_enum
{
	blink_state_4_high = 8,
	blink_state_4_low  = 7,
	blink_state_3_high = 6,
	blink_state_3_low  = 5,
	blink_state_2_high = 4,
	blink_state_2_low  = 3,
	blink_state_1_high = 2,
	blink_state_1_low  = 1,
	blink_state_0      = 0,
} blink_state_t;

extern volatile bool ADCResRdy;

void ledUsrBlink(uint8_t count, const int blinkPeriodMsec);


#endif /* MAIN_H_ */

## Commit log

2021-12-12 Initial commit
    Moving a working blinky project between computers
    This project will need to be moved out of XC8Application1 of course, but for now it's just a blinky running on my PCB
2021-12-16 Partial progress- USR_LED and PIR working, display NOT working.
    Transferring between computers- as mentioned the USR LED and the PIR sensor are currently working as expected, but the display is not. I'm hoping this is just a software issue.
    [I2C.c, main.c, main.h]
2021-12-17 Basic CutWires functionality implemented.
    Tested the cutWires pinout enough to determine the attiny's pullup resistors will suffice (no external ones needed for V2), and tested reading on those input pins.
2022-01-13 Parameterize prog_cmd, skeleton for audio, display working
    I2C display is working fully now, audio is starting to get built out but doesn't work yet. Remove computer directory info from the .cproj file (granted, not extremely helpful on its own to make the programming command generic- would need a way to let user set their own COM port).
    Next step will be a move/refactor of the software folder, and some rebasing of files for clean-up's sake
    [I2C.c, main.c, main.h]
2022-01-13 Rename and move project
    Project still doing the same thing when flashed to the ATTiny, but now it has a non-Microchip-Studio default name and is in a more proper folder. This may still be extremely brittle/ not work for anyone else, but that can be addressed if necessary later.
    [I2C.c, main.c, main.h]
2022-01-14 Code cleanup and function comments
    Really basic small quality of life stuff- admittedly did not clean up the ugliest part here (the i2c in initSevenSeg() )
2022-01-20 Separate sevenSeg file, countdown interrupt working
    * SevenSeg logic in its own file
    * Still TODO get countdown timing correct, but some kind of countdown is happening
    * TODO get timing correct
    * TODO implement state machine for PIR sensor and cut wires
    * Farther off get audio minimally working
    [SevenSeg.c, SevenSeg.h, main.c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]
2022-01-21 Beginnings of state machine
    * Start to setup board state as it will be in the project
    * Helper function for blinking the sevenSeg display
    * Global interrupt enable and improvement to countdown timer int vector
2022-01-26 CutWires logic working, random cutwire, simplify SevenSeg config
    * CutWires logic appears to be mostly working as final
    * Random and random seed-via-ADC input working
    * Simplify SevenSeg initial config via convenience function
    * Simplify setting all sevenSeg digits the same via convenience function
2022-01-26 Disagreeable newline silliness
    Somehow my IDE started mixing in Windows CRs into main.c and everything got messed up. This CL is mostly just formatting to avoid obscuring real changes.
    [SevenSeg.c, SevenSeg.h, main.c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]
2022-01-29 wireCut logic working, PIR sensitivity tuned to require more movement
    * PIR sensitivity is near to endgame, and it can be further tuned if appropriate
    * Wire cut logic is now set up properly and applied in main() corrrectly.
    * SevenSeg blink logic changed to allow for different blink rates
    * WriteAllDigits name changed to reflect that it applies changes
    * More comments throughout
2022-01-31 Audio now working
    With this, despite some errata, all major components of the board are verified.
    The audio is working, despite some misunderstandings here and there. Unfortunately the audio is horribly loud also, so the final board will hopefully address some improvements that can be made there.
    Had to change TCA0 to Split, as misunderstandings during the board layout forced me to use split mode in order to get an output.
    [main.c]
2022-01-31 Add SetAudioIsEnabled function, temporarily mute audio until it can be quieted a bit
    Next board spin will fix this with a trim pot of some sort.
    [main.c]
2022-02-01 Add hardware, improve README
    Resolves #1 #2 #3 #4 via this new 2.0 board design, hopefully the final for this project. Also add PDF and PNG files, to later be included into the README
    [Annoyatron_v2-B_Cu.gbl, Annoyatron_v2-B_Mask.gbs, Annoyatron_v2-B_Paste.gbp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]
2022-02-01 Create Annoyatron_v2_BOM.csv
    Adding the bill of materials in CSV format for the project.
    [Annoyatron_v2_BOM.csv]
2022-05-11 Support ATTiny1606 rather than 406, use SET/CLR
    Original project ran on a 16k mcu, so needed to swap to an ATTiny 1606- this required some changes to the pinout and to especially the PWM. Also the audio is re-enabled in this commit.
    [main.c]
2022-05-12 Implement full legacy state machine
    With these changes, the project is now feature-complete with the version originally created on msp430 in 2014.
    There are still some things on the wish list, like
    * Low power mode while waiting on PIR wakeup
    * Better audio quality and less high pitch ringing
    * Better sample rate, effective value between TCA_SPLIT_CLKSEL_DIV2_gc and TCA_SPLIT_CLKSEL_DIV1_gc
    * Full Doxygen support and documentation
    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
2022-05-29 Add countdown blinking
    One item from the wishlist was to have LEDs flash out the pattern of the wire to cut quickly but still understandably. This change adds a state machine and non-blocking logic to the countdown timer i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
2022-06-05 Update BOM and Schematic
    [Annoyatron_v2_BOM.csv]
2022-06-05 Add BOM description, correct references from ATTiny406 to proper ATTiny1606
    Just these two things, a helpful description to the BOM to de-mystify some components, and reflecting that this project strictly requires an ATTiny1606 microcontroller to hold the raw audio data.
    [Annoyatron_v2_BOM.csv]
2024-01-08 Refactored statemachine/ ISRs to work with sleep
    This commit changes the "board_state_waiting" state such that instead of endlessly waiting for enough consecutive PIR detects to enter countdown mode, it now is prepared to fall down to a atTINY 1606 sleep mode (exact sleep mode to be determined). Hysteresis is also added to this "fall to sleep" counter so that the board does not thrash too much between low power mode and wakeup during intermittent detection.
    The board appears to behave nominally with these changes.
    NOTE: for the moment the sleep command is disabled, though the preparations have mostly been made for it to be enabled. .
    [main.c, main.h]
2024-01-08 Enable Sleep mode, demonstrate reduced current
    Nominal behavior continues with Sleep mode enabled.
    That pretty much wraps this feature branch.
    Confirmed via multimeter across the power switch that the current consumption drops consistently by 2mA for the entire PCB when the device indicates PWR_DOWN sleep mode. Further improvements in power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
2024-01-08 Improve generated Doxygen
    Changes to documentation to improve the output Doxygen, seeing as anyways the code has changed and thus the Doxygen must as well. The changes to the Doxyfile are fairly significant and resolve some long-standing frustrations I'd had with the layout of the resulting HTML, especially with regards to finding the "Files" pages.
    [I2C.c, SevenSeg.c, SevenSeg.h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]
2024-01-14 Add parseWaveFile.py script and README
    move audio stuff to a folder for organization's sake and as promised document the kind of cool process of landing on the new final audio samples for "youWin" and "youLose" and the challenges that wer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
2024-01-14 BUGFIX transition from wire_setup state to sleep
    Going from wire_setup to waiting state just wasn't working properly, so fix some aspects of that transition so that now the state and the LED are predictable at the cost of some responsiveness in a state where responsiveness is not that important.
    [main.c]
2024-01-14 Add Powershell Scripts used during development
    These are scripts that I used and would like to keep around if this project is revisited in the future. It is trivial to imagine converting them to bash or whatever shell- the key is just having pymcuprog in the path and the rest is trivial. The main scripts used here are `EraseATTiny.ps1` which I used before every re-flash of the board during development, `ProgramATTIny.ps1` which I didn't actually use directly but instead fed into a build configuration of Microchip Studio and used as my "Start Without Debugging" command, and `WriteATTinyResetFuse_DESTRUCTIVE.ps1` which I used at the end of the project to enable the reset button by reconfigurin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
